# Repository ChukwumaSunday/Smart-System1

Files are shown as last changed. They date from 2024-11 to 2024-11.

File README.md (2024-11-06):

Pro-Tracking 4G LTE Solution Board
Pro-Tracking Solution Board is an ecosystem friendly onboard tracking technology and multi-functional development board based on STM32 microcontroller, designed to meet the requirements of embedded systems, vehicles/general tracking, providing a comprehensive set of features and peripherals on a single chip. The system is optimized for low power consumption and real-time processing, making it suitable for a wide rand of application
Pro-Tracking 4G LTE offers wide range of capabilities and features, making it ideal for use in many different types of applications.  This system can be used in consumer products such as appliances remote controls, motor control systems, medical devices, gaming console, home automation systems and more.
A Pro-Tracking 4G LTE integrated two types of the 4G LTE CAT4 module SIM7600A-H or SIM7600E-H, SIM7600A-H/SIM7600E-H is a complete multi-band LTE-FDD/LTE-TDD/HSPA+/UMTS/EDGE/GPRS/GSM module solution in LCC type which supports LTE CAT4 up to 150Mbps for downlink and 50Mbps for uplink data transfer, much faster and popular than 2G/3G.
 
Board Interface 

 



Features
•	Supports dial-up, phone, SMS, TCP, UDP, DTMF, HTTP, FTP, and so on
•	Dual USB Type C port
•	Control Via AT Commands
•	Board USB supply voltage range: 4.8~5.5V, 5.0V Typical
•	Board Battery supply voltage range: 3.4~4.2V, 3.7V Typical
•	3GPP E-UTRA Release 11
•	Onboard charger, up to 1A charge current
•	Overcharge protection(OCP), 4.3V
•	Over-discharge protection(ODP), 2.5V
•	Power Manager, the board can be supplied by USB or battery.
•	IPEX Antenna, GSM/UMTS/LTE main antenna. UMTS/LTE auxiliary antenna. GNSS antenna
•	SMS support
•	Audio support
•	On board controller: STM32F411CEU6
•	Support  STM32CUBE IDE 
•	Audio Codec: NAU8810
•	Level Shifter: TXS0108E
•	Windows and Raspberry Pi support
•	Qualcomm MDM9x07 Chipset
•	On  board Sensor : MPU-6050 (Accelerometer/Gyroscope)
•	On  board Sensor 256MB flash memory: W25Q32JVSSIQ
Current Stage
The PCB development stage is almost done
Challenges
•	Time
•	Sourcing of component
•	Getting quality component elements
Requirements
Finance to fund the project

Usage
Warning: Do not operate when in power on (don’t plug or unplug the Antenna, SIM Cards, SD Card, in case of short-circuiting that may burn the IC down.)
Hardware connection
1. Plug the SIM card into the board.
2. Plug the GPS antenna into the interface.
3. Plug two 4G-GSM antennas into the main antenna interface and auxiliary one.
4. Plug the headphone with the microphone.
5. Plug the SD card into the SD card slot for SIM7600.
When powering the board and the SIM7600 module working, the onboard STA LED (blue) will turn on.
Possible projects with Pro-tracking Solution Board
1.	GPS Tracker - SMS & Battery Monitor 
2.	Send Location & Make Call using SOS Button _ IOT Projects _ GPS Projects
3.	Embedded Systems applications
4.	IoT applications
5.	This system can be used in consumer products such as 
•	Appliances remote controls
•	Vehicles/Location Tracking
•	Motor control systems
•	Medical devices
•	Gaming console
•	Home automation systems and more.

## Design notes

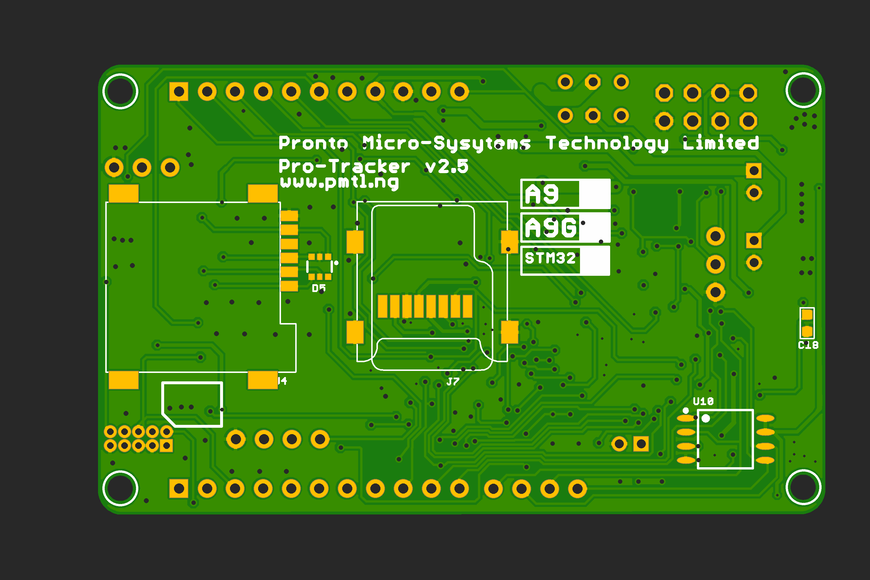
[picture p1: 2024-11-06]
Pro-Tracker(A9 STM32F411CEU6)/stm32_tracker34_Bottom.png

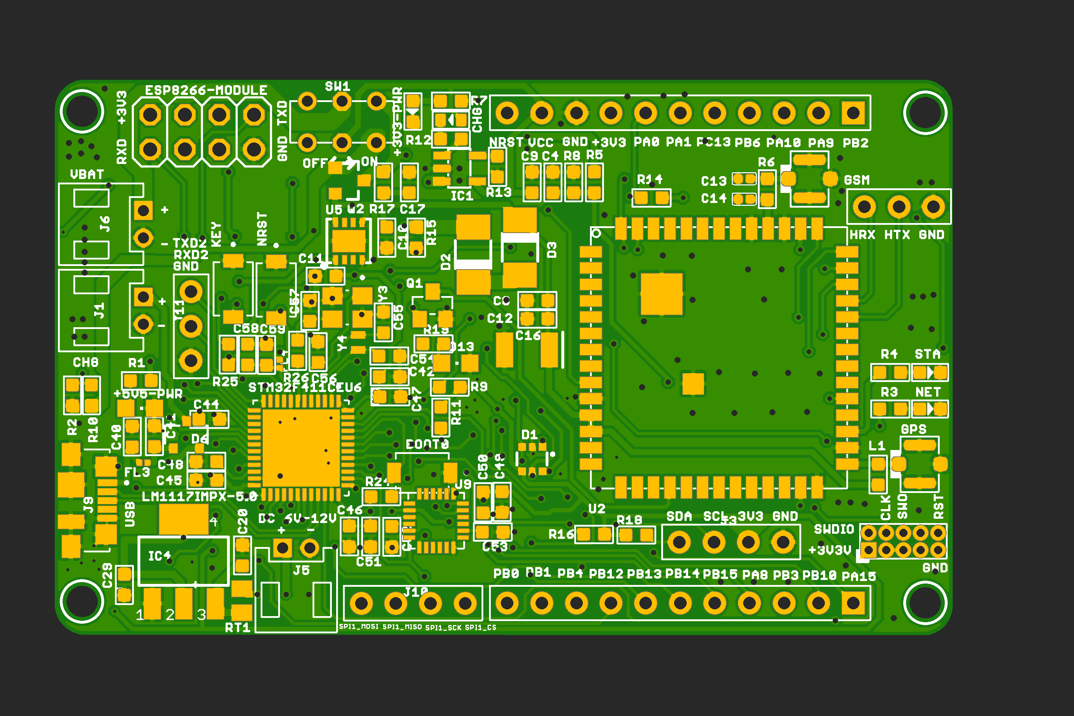
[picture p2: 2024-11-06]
Pro-Tracker(A9 STM32F411CEU6)/stm32_tracker34_Top.png

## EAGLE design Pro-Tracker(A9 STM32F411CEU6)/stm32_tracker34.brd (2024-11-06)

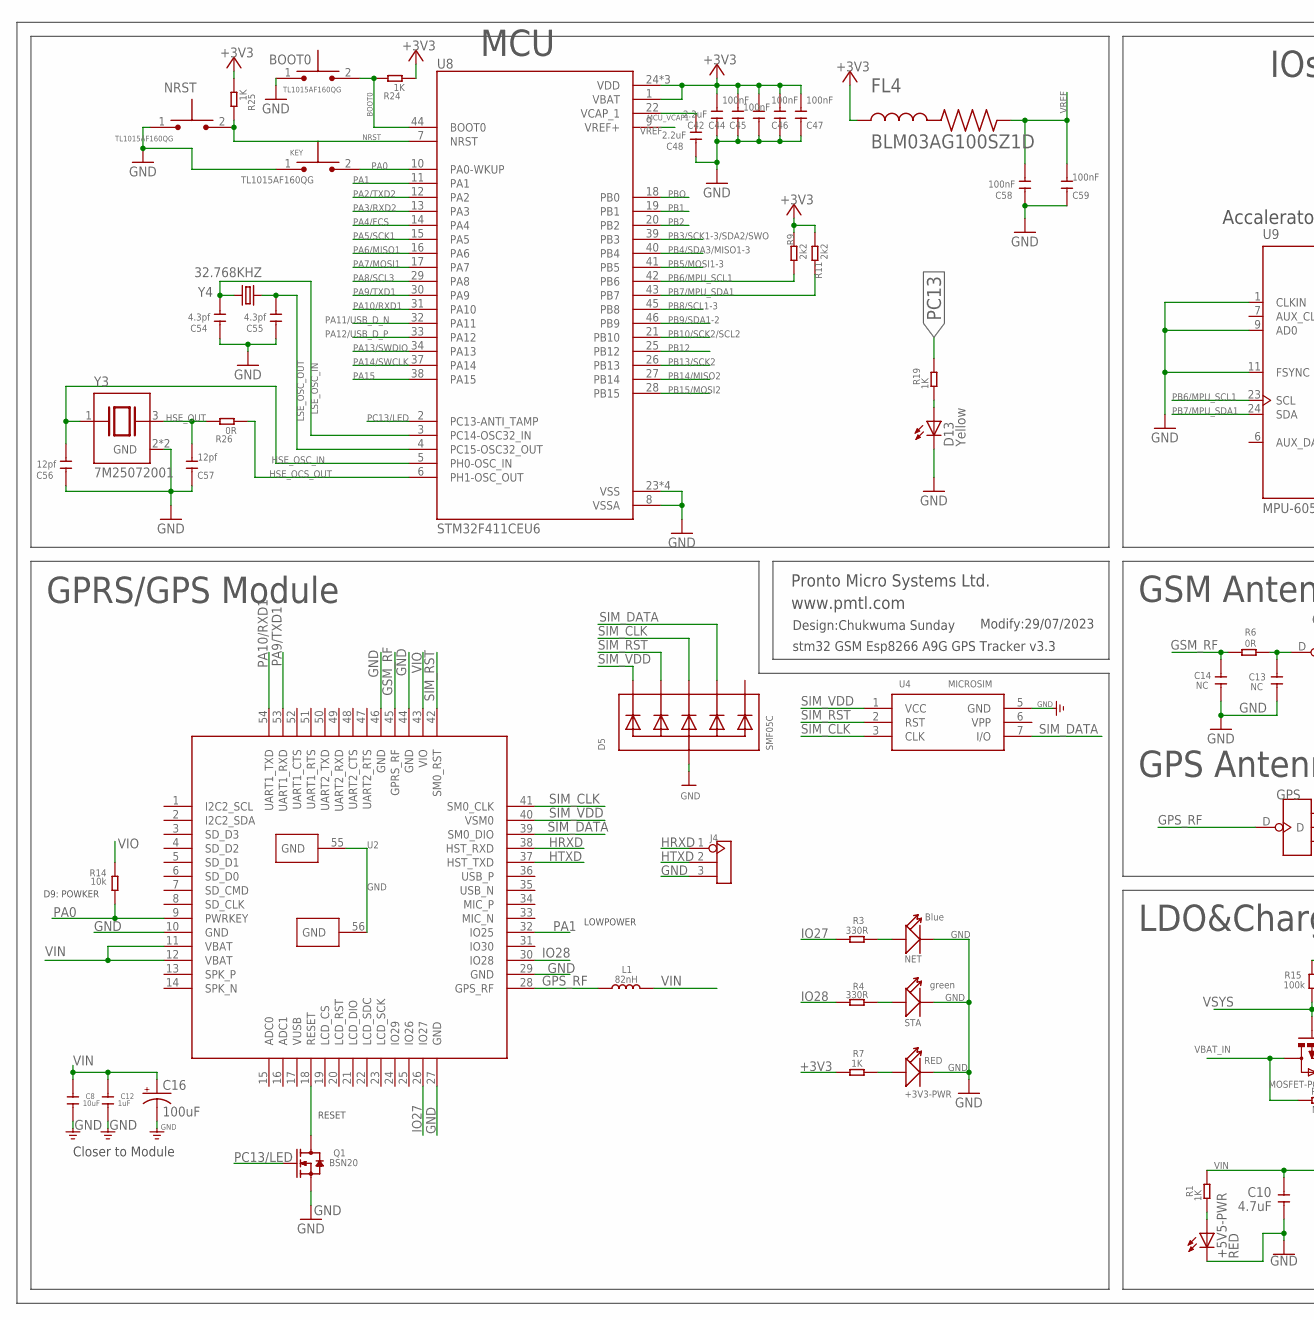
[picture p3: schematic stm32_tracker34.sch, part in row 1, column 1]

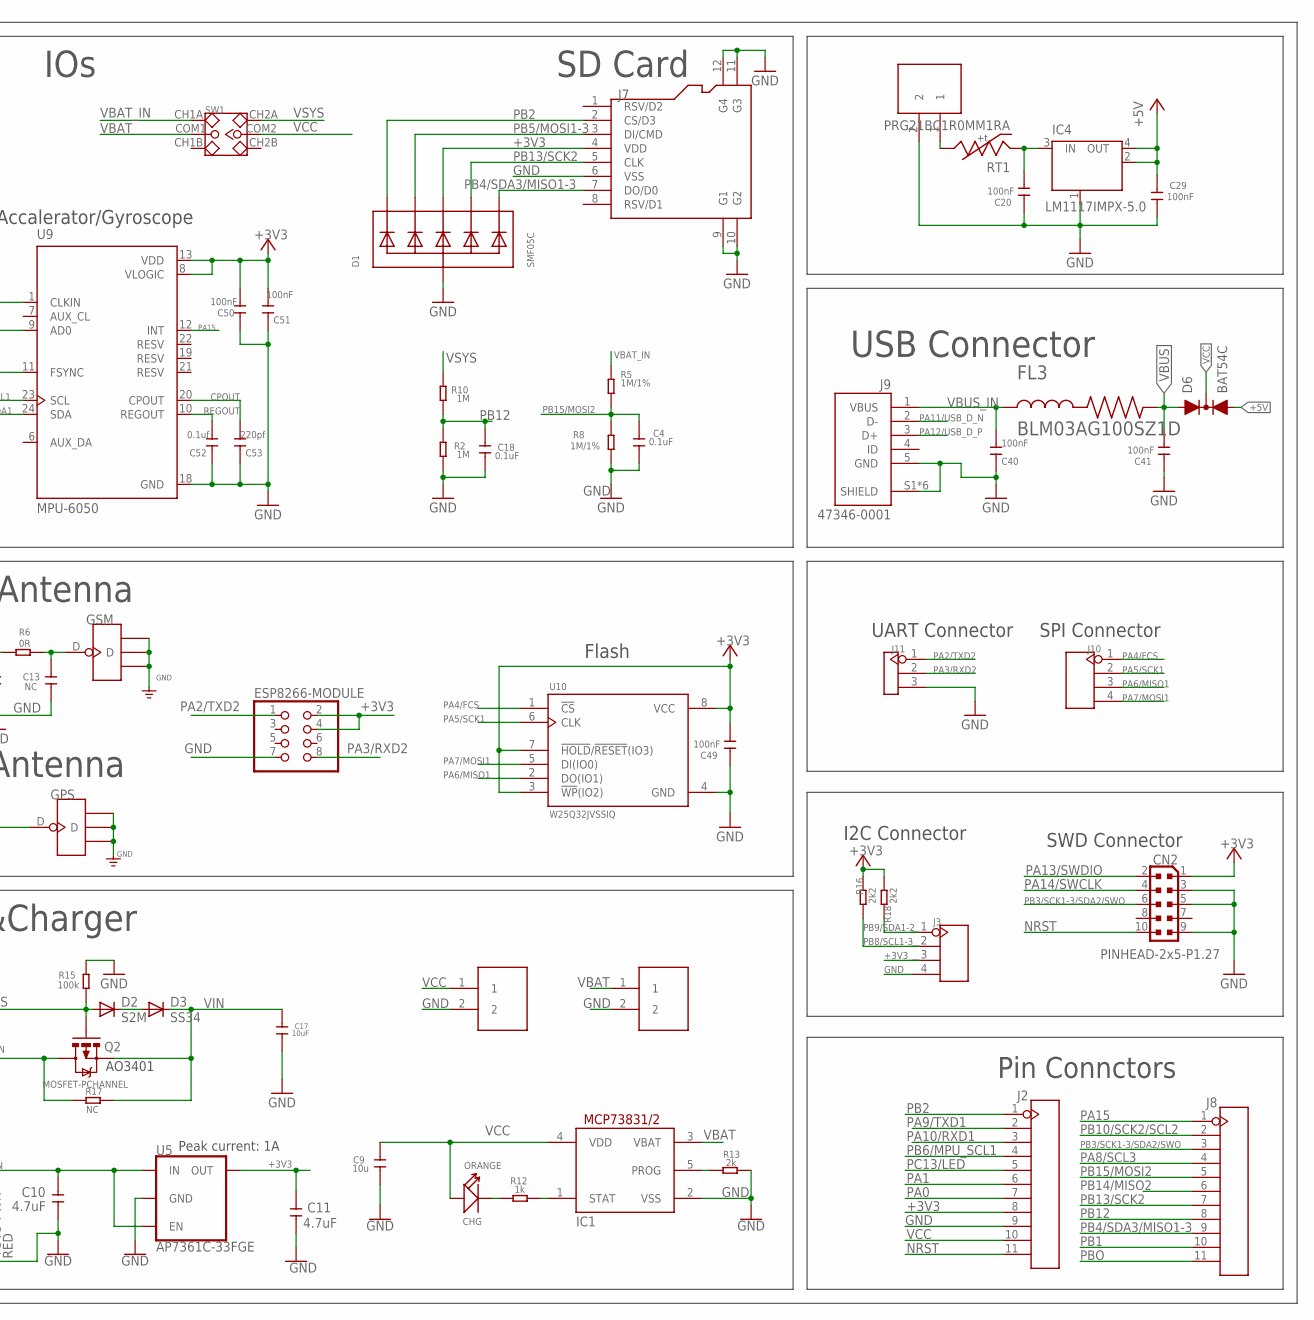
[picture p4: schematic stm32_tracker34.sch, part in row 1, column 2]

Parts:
+3V3-PWR: RED; LED-0603
+5V5-PWR: RED; OPTO_CHIPLED_0805
BOOT0: TL1015AF160QG; SW_TL1015AF160QG
C4, C18: 0.1uF; C0603
C8, C17: 10uF; C0603
C9: 10u; C0603
C10, C11: 4.7uF; C0603
C12: 1uF; C0603
C13, C14: NC; C0402
C16: 100uF; EIA3528
C20, C29, C40, C41, C44, C45, C46, C47, C49, C50, C51, C58, C59: 100nF; C0603
C42, C48: 2.2uF; C0603
C52: 0.1uf; C0603
C53: 220pf; C0603
C54, C55: 4.3pf; C0603
C56, C57: 12pf; C0603
CHG: ORANGE; D0603
CN2: PINHEAD-2x5-P1.27; PINHEAD_2X05_127
D1, D5: SMF05C; SOT363
D2: S2M; DO-214AC
D3: SS34; DO-214AC
D6: BAT54C; SOT23-R
D13: Yellow; OPTO_CHIPLED_0805
ESP8266-MODULE: PINHD-2X4; 2X04
FL3, FL4: BLM03AG100SZ1D; BEADC0603X33N
GPS: ANTENNA-U-FL; 4P-U-FL
GSM: ANTENNA-U-FL; 4P-U-FL
IC1: MCP73831/OT; SOT23-5L
IC4: LM1117IMPX-5.0; INTEGRATEDCIRCUITS_LINEAR_SOT223
J1, J5, J6: PH2.0-2P-90-DIP
J2, J8: HEADER-11P-2.54; 11P-2.54
J3, J10: HEADER-4P-60/35MILROUND; 4P-65/35ROUND
J4, J11: HEADER-3P-2.54; 3P-2.54
J7: HOLDER-MICROSD-8P; 8P-SMD
J9: 47346-0001; MOLEX_47346-0001
KEY: TL1015AF160QG; SW_TL1015AF160QG
L1: 82nH; L0603
NET: Blue; LED-0603
NRST: TL1015AF160QG; SW_TL1015AF160QG
Q1: BSN20; SOT23@1
Q2: MOSFET-PCHANNEL; SOT23-3
R1, R7, R19, R24, R25: 1K; R0603
R2, R10: 1M; R0603
R3, R4: 330R; R0603
R5, R8: 1M/1%; R0603
R6, R26: 0R; R0603
R9, R11, R16, R18: 2k2; R0603
R12: 1k; R0603
R13: 2k; R0603
R14: 10k; R0603
R15: 100k; R0603
R17: NC; R0603
RT1: PRG21BC1R0MM1RA; THRMC2012X110N
STA: green; LED-0603
SW1: SWITCH-2CH-6P; 6P-2CH-2.54-7.6X3.0
U2: A9G
U4: MICROSIM
U5: AP7361C-33FGE; 8-UDFN
U8: STM32F411CEU6; QFN50P700X700X60-49N
U9: MPU-6050; QFN50P400X400X95-24N
U10: W25Q32JVSSIQ; SOIC127P790X216-8N
Y3: 7M25072001; XTAL_7M25072001
Y4: 32.768KHZ; XTAL160X100X50

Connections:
+3V3: C11.2, C42.2, C44.2, C45.2, C46.2, C47.2, C49.2, C50.2, C51.2, CN2.1, D1.4 (C3), ESP8266-MODULE.2, ESP8266-MODULE.4, FL4.1, J2.8, J3.3, J7.4 (VDD), R7.1, R9.1, R11.1, R16.1, R18.1, R24.1, R25.1, U5.1 (OUT), U8.1 (VBAT), U8.24 (VDD), U8.36 (VDD), U8.48 (VDD), U9.8 (VLOGIC), U9.13 (VDD), U10.3 (!WP!(IO2)), U10.7 (!HOLD!/!RESET!(IO3)), U10.8 (VCC)
+5V: C29.1, D6.2 (A2), IC4.2 (OUT), IC4.4 (OUT)
A9_RESET: Q1.3 (D), U2.18 (RESET)
BOOT0: BOOT0.2, R24.2, U8.44 (BOOT0)
CPOUT: C53.2, U9.20 (CPOUT)
GND: +3V3-PWR.-, +5V5-PWR.C, BOOT0.1, C4.2, C8.1, C9.1, C10.1, C11.1, C12.1, C13.1, C14.1, C16.C (-), C17.1, C18.2, C20.1, C29.2, C40.1, C41.1, C42.1, C44.1, C45.1, C46.1, C47.1, C48.1, C49.1, C50.1, C51.1, C52.1, C53.1, C54.1, C55.1, C56.1, C57.1, C58.1, C59.1, CN2.3, CN2.5, CN2.9, D1.2 (A), D5.2 (A), D13.C, ESP8266-MODULE.7, GPS.GND1, GPS.GND2, GPS.GND3, GSM.GND1, GSM.GND2, GSM.GND3, IC1.2 (VSS), IC4.1 (GND/ADJ), J1.2, J2.9, J3.4, J4.3, J5.2, J6.2, J7.6 (VSS), J7.9 (G1), J7.10 (G2), J7.11 (G3), J7.12 (G4), J9.5 (GND), J9.S1 (SHIELD), J9.S2 (SHIELD), J9.S3 (SHIELD), J9.S4 (SHIELD), J9.S5 (SHIELD), J9.S6 (SHIELD), J11.3, KEY.1, NET.-, NRST.1, Q1.2 (S), R2.1, R8.1, R13.2, R15.2, STA.-, U2.10 (GND), U2.27 (GND), U2.29 (GND), U2.44 (GND), U2.46 (GND), U2.55 (GND), U2.56 (GND), U4.5 (GND), U5.4 (GND), U5.EP (GND), U8.8 (VSSA), U8.23 (VSS), U8.35 (VSS), U8.47 (VSS), U8.49 (VSS), U9.1 (CLKIN), U9.9 (AD0), U9.11 (FSYNC), U9.18 (GND), U10.4 (GND), Y3.2 (GND), Y3.4 (GND)
GPS_RF: GPS.D, L1.1, U2.28 (GPS_RF)
GSM_RF: C14.2, R6.1, U2.45 (GPRS_RF)
HRXD: J4.1, U2.38 (HST_RXD)
HSE_OCS_OUT: R26.1, U8.6 (PH1-OSC_OUT)
HSE_OSC_IN: C56.2, U8.5 (PH0-OSC_IN), Y3.1
HSE_OUT: C57.2, R26.2, Y3.3 (2)
HTXD: J4.2, U2.37 (HST_TXD)
IO27: R3.1, U2.26 (IO27)
IO28: R4.1, U2.30 (IO28)
LSE_OSC_IN: C54.2, U8.3 (PC14-OSC32_IN), Y4.2
LSE_OSC_OUT: C55.2, U8.4 (PC15-OSC32_OUT), Y4.1
MCU_VCAP1: C48.2, U8.22 (VCAP_1)
unnamed: R4.2, STA.+
unnamed: D2.C, D3.A
unnamed: +3V3-PWR.+, R7.2
unnamed: J5.1, RT1.2
unnamed: +5V5-PWR.A, R1.1
unnamed: C20.2, IC4.3 (IN), RT1.1
unnamed: NET.+, R3.2
unnamed: D13.A, R19.1
unnamed: CHG.-, R12.1
unnamed: IC1.1 (STAT), R12.2
unnamed: IC1.5 (PROG), R13.1
unnamed: C13.2, GSM.D, R6.2
NRST: CN2.10, J2.11, NRST.2, R25.2, U8.7 (NRST)
PA0: J2.7, KEY.2, R14.1, U2.9 (PWRKEY), U8.10 (PA0-WKUP)
PA1: J2.6, U2.32 (IO25), U8.11 (PA1)
PA2/TXD2: ESP8266-MODULE.1, J11.1, U8.12 (PA2)
PA3/RXD2: ESP8266-MODULE.8, J11.2, U8.13 (PA3)
PA4/FCS: J10.1, U8.14 (PA4), U10.1 (!CS)
PA5/SCK1: J10.2, U8.15 (PA5), U10.6 (CLK)
PA6/MISO1: J10.3, U8.16 (PA6), U10.2 (DO(IO1))
PA7/MOSI1: J10.4, U8.17 (PA7), U10.5 (DI(IO0))
PA8/SCL3: J8.4, U8.29 (PA8)
PA9/TXD1: J2.2, U2.53 (UART1_RXD), U8.30 (PA9)
PA10/RXD1: J2.3, U2.54 (UART1_TXD), U8.31 (PA10)
PA11/USB_D_N: J9.2 (D-), U8.32 (PA11)
PA12/USB_D_P: J9.3 (D+), U8.33 (PA12)
PA13/SWDIO: CN2.2, U8.34 (PA13)
PA14/SWCLK: CN2.4, U8.37 (PA14)
PA15: J8.1, U8.38 (PA15), U9.12 (INT)
PB1: J8.10, U8.19 (PB1)
PB2: D1.1 (C1), J2.1, J7.2 (CS/D3), U8.20 (PB2)
PB3/SCK1-3/SDA2/SWO: CN2.6, J8.3, U8.39 (PB3)
PB4/SDA3/MISO1-3: D1.6 (C5), J7.7 (DO/D0), J8.9, U8.40 (PB4)
PB5/MOSI1-3: D1.3 (C2), J7.3 (DI/CMD), U8.41 (PB5)
PB6/MPU_SCL1: J2.4, R9.2, U8.42 (PB6), U9.23 (SCL)
PB7/MPU_SDA1: R11.2, U8.43 (PB7), U9.24 (SDA)
PB8/SCL1-3: J3.2, R16.2, U8.45 (PB8)
PB9/SDA1-2: J3.1, R18.2, U8.46 (PB9)
PB10/SCK2/SCL2: J8.2, U8.21 (PB10)
PB12: C18.1, J8.8, R2.2, R10.1, U8.25 (PB12)
PB13/SCK2: D1.5 (C4), J7.5 (CLK), J8.7, U8.26 (PB13)
PB14/MISO2: J8.6, U8.27 (PB14)
PB15/MOSI2: C4.1, J8.5, R5.1, R8.2, U8.28 (PB15)
PBO: J8.11, U8.18 (PB0)
PC13: R19.2
PC13/LED: J2.5, Q1.1 (G), U8.2 (PC13-ANTI_TAMP)
REGOUT: C52.2, U9.10 (REGOUT)
SIM_CLK: D5.4 (C3), U2.41 (SM0_CLK), U4.3 (CLK)
SIM_DATA: D5.5 (C4), U2.39 (SM0_DIO), U4.7 (I/O)
SIM_RST: D5.3 (C2), U2.42 (SM0_RST), U4.2 (RST)
SIM_VDD: D5.1 (C1), U2.40 (VSM0), U4.1 (VCC)
VBAT: IC1.3 (VBAT), J6.1, SW1.COM1
VBAT_IN: Q2.3 (D), R5.2, R17.1, SW1.CH1A
VBUS: C41.2, D6.1 (A1), FL3.2
VBUS_IN: C40.2, FL3.1, J9.1 (VBUS)
VCC: C9.2, CHG.+, D6.3 (C), IC1.4 (VDD), J1.1, J2.10, SW1.COM2
VIN: C8.2, C10.2, C12.2, C16.A (+), C17.2, D3.C, L1.2, Q2.2 (S), R1.2, R17.2, U2.11 (VBAT), U2.12 (VBAT), U5.5 (EN), U5.8 (IN)
VIO: R14.2, U2.43 (VIO)
VREF: C58.2, C59.2, FL4.2, U8.9 (VREF+)
VSYS: D2.A, Q2.1 (G), R10.2, R15.1, SW1.CH2A

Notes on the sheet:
GSM Antenna
GPRS/GPS Module
LOWPOWER
RESET
D9: POWKER
Peak current: 1A
www.pmtl.com
IOs
LDO&Charger
GPS Antenna
Design:Chukwuma Sunday
Modify:29/07/2023
Pronto Micro Systems Ltd.
Closer to Module
AO3401
stm32 GSM Esp8266 A9G GPS Tracker v3.3
MCU
USB Connector
Flash
SWD Connector
Accalerator/Gyroscope
Pin Connctors
SD Card
SPI Connector
UART Connector
I2C Connector

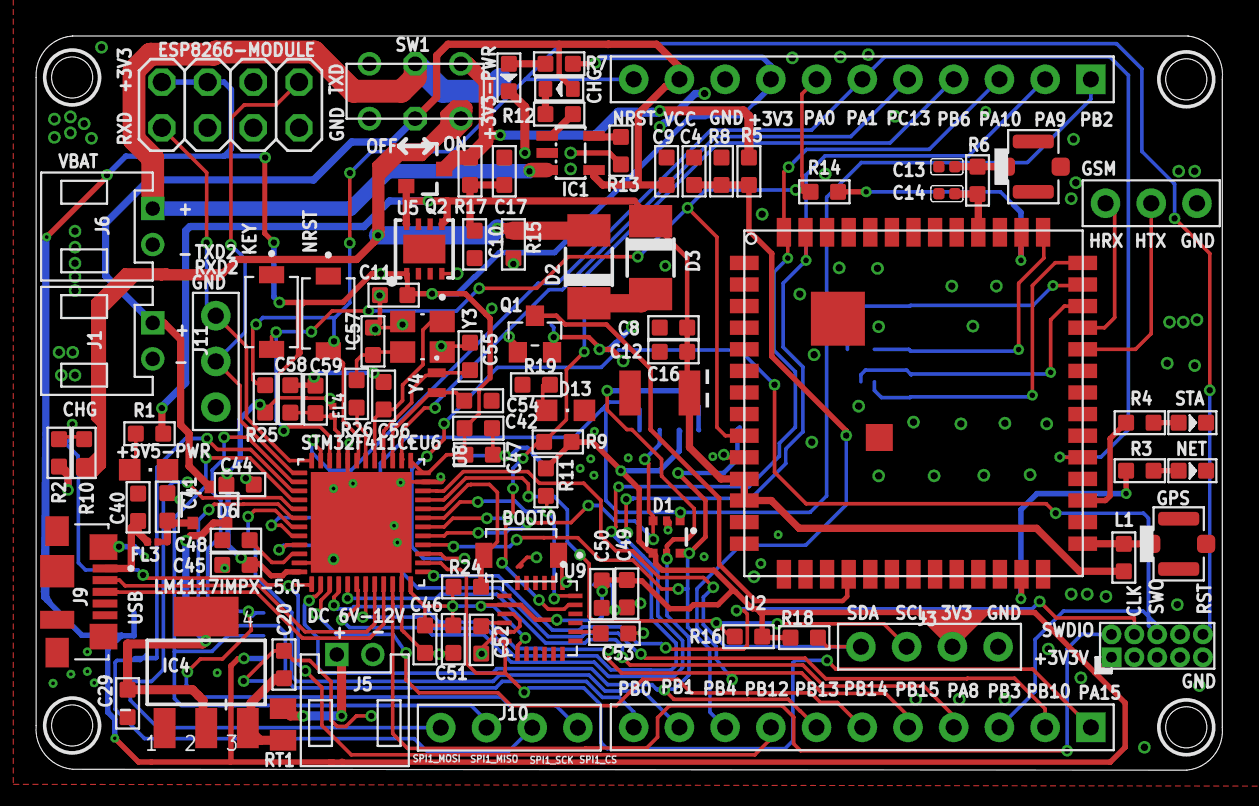
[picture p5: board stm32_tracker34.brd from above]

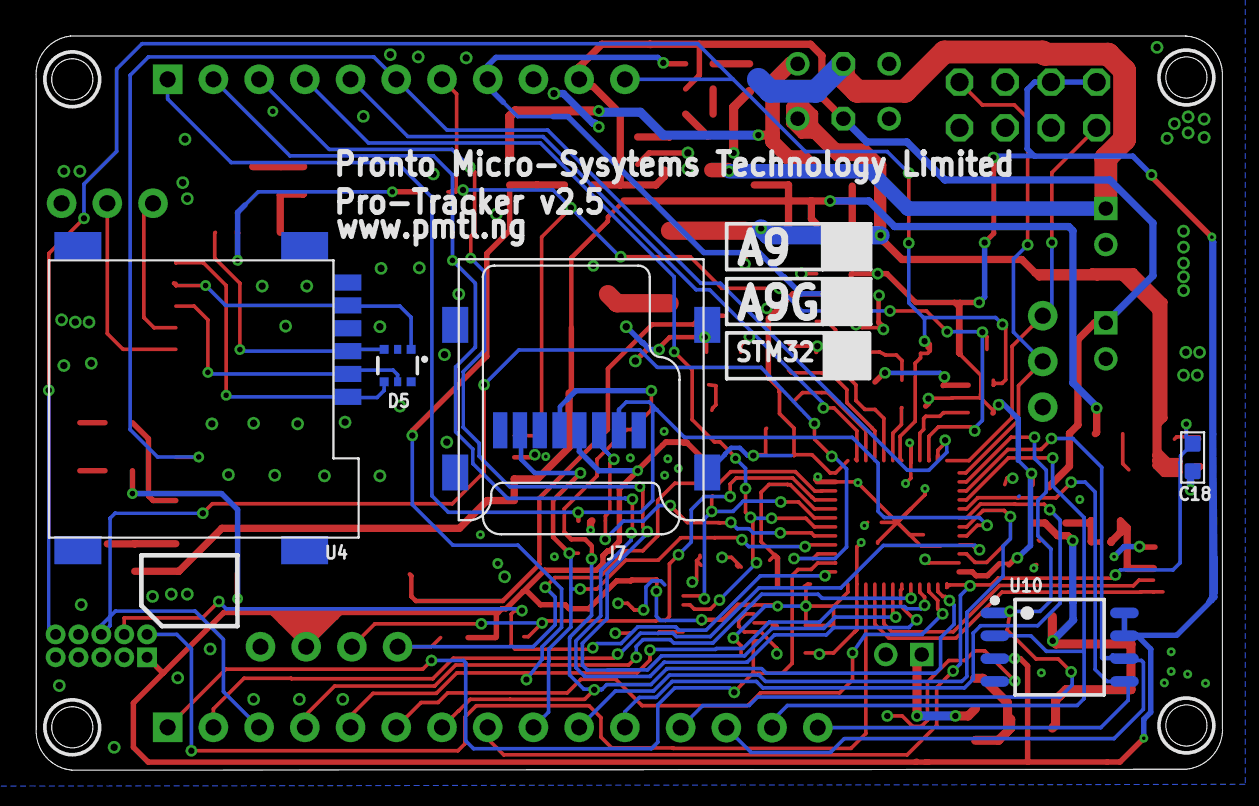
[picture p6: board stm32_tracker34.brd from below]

Board: 2 copper layers, 65.9 x 40.8 mm, 100 parts (5 on the bottom side), 77 nets.

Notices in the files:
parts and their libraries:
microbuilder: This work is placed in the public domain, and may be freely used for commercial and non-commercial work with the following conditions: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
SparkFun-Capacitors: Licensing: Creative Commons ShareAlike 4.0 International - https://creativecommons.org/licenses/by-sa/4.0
